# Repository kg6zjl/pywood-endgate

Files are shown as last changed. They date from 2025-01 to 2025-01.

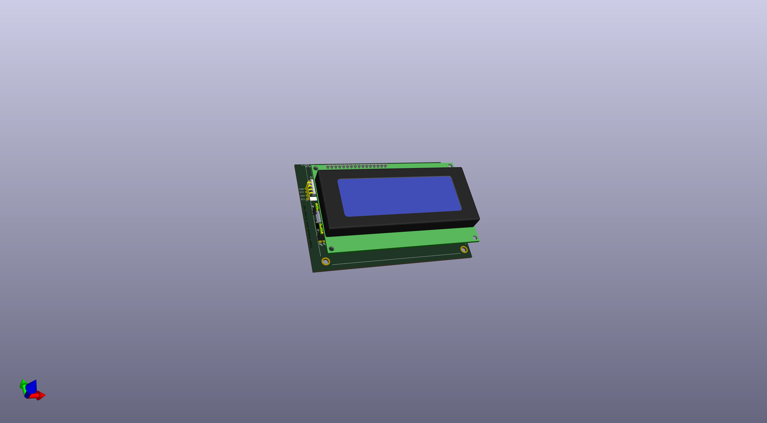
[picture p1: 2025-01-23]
hw/pine_derby_hw1.jpg

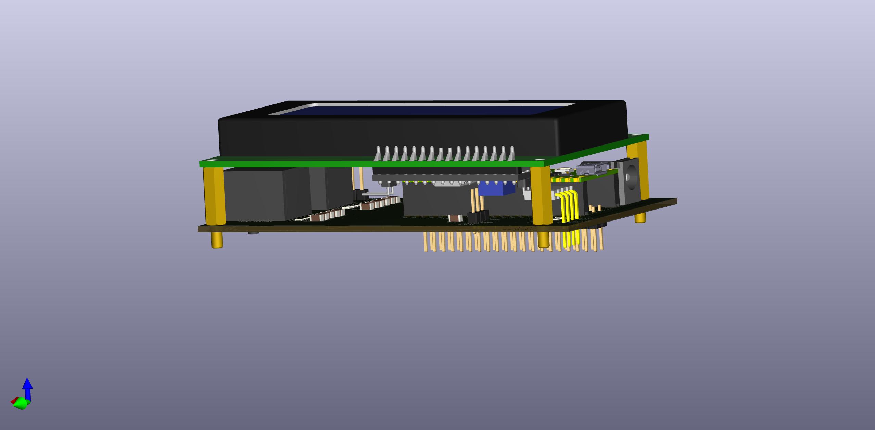
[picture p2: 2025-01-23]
hw/exports/pine_derby_hw_3.jpg

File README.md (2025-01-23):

Our scouting troop in TrailLifeUSA needs a way to identify which Pinewood Derby cars place first and second. We run two brackets, one for first place and one for second. Our current track is a 4 lane with manually operated lever gate for release.

I decided that from a K.I.S.S. standpoint, I don't care about timing the cars. Could be a future state, but for this iteration it doesn't matter. We really only care about the order that the cars reach the end gate.

This is my first time ever working at a PIO/hardware level, so feedback is appreciated. I'm learning along the way!

# Initial Design
- Micropython as the language
- Waveshare RP2040 Plus as the MCU
- 4 Row LCD for results
- A momentary reset button to trigger a display reset
- Light Dependent Resistors (Digital Module LM393) under the track, existing light source in endgate as primary light source

# Future State/Improvements/Ideas
- Add duplicate display at start gate so that bracket manager can see results on stage
- Add a microswitch at the start gate and add timing functionality
- Print race slips for winners with times? could be fun
- A camera/photo of the winner would be fun, especially if we setup a projector
- Automated bracket tracking?
- IR Break Beam sensors for end gate (introduces slightly more wiring, but same amount of programatic complexity I think)

# Notes
- When loading up RP2040, you have to load MicroPython first (see firmware)
- Then you have to copy all the project files over to RP2040
- Click "Run" in VSCode

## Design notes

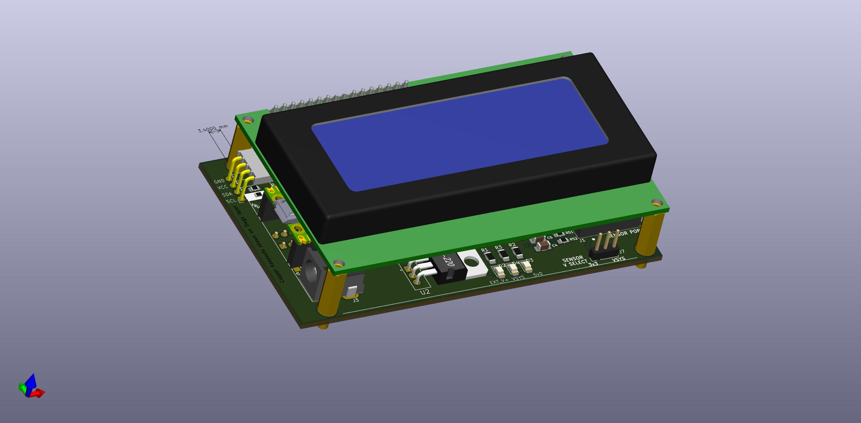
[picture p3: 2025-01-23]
hw/exports/pine_derby_hw_1.jpg

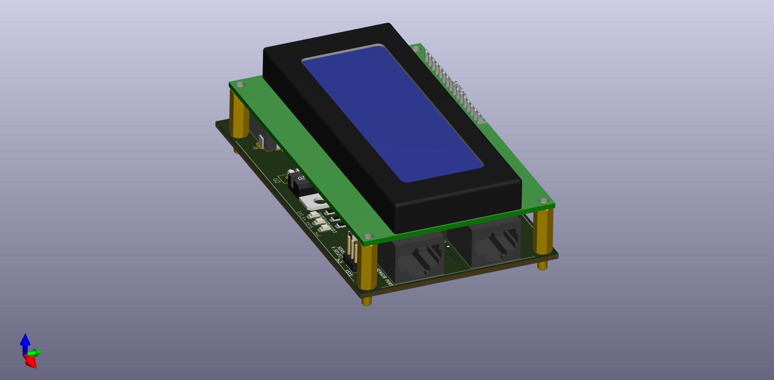
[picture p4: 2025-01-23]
hw/exports/pine_derby_hw_2.jpg

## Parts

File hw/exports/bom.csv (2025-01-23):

Reference | Value | Datasheet | Footprint | Qty | DNP | MPN
J3 | PJ-202AH | ~ | PJ-202AH:CUI_PJ-202AH | 1 |  | PJ-202AH
U2 | L7805CV |  | L7805CV:TO255P1040X460X1968-3 | 1 |  | L7805C-V
J1,J2 | 54602-908LF |  | 54602-908LF:AMPHENOL_54602-908LF | 2 |  | 54602-908LF
U1 | Pico |  | MCU_RaspberryPi_and_Boards:RPi_Pico_SMD_TH | 1
R4,R5,R6,R7,R8,R9,R10,R11,R12,R13,R14,R15,R16,R17,R18,R19,R20,R21,R22,R23,R24,R25,R26,R27,R28,R29,R30,R31,R32,R33,R34,R35,R36,R37,R38,R39,R40,R41,R42,R43,R44,R45,R46,R47,R48,R49,R50,R51,R52,R53,R54,R55,R56 | 0R | ~ | Resistor_SMD:R_0805_2012Metric_Pad1.20x1.40mm_HandSolder | 53 |  | RC0805JR-070RL
R1,R2,R3 | 3k | ~ | Resistor_SMD:R_1206_3216Metric_Pad1.30x1.75mm_HandSolder | 3 |  | RC1206JR-073KL
J6,J7 | Conn_01x03_Pin | ~ | Connector_PinHeader_2.54mm:PinHeader_1x03_P2.54mm_Vertical | 2 |  | 61300311121
J4,J5 | Conn_01x20_Pin | ~ | Connector_PinHeader_2.54mm:PinHeader_1x20_P2.54mm_Vertical | 2 |  | PH1-20-UA
DS1 | LCD-20X4B |  | LCD-20X48:LCD_LCD-20X4B | 1
D2,D3,D4 | LED-G | ~ | LED_SMD:LED_1206_3216Metric_Pad1.42x1.75mm_HandSolder | 3 |  | LTST-C150GKT
D1 | D | ~ | Diode_SMD:Nexperia_CFP3_SOD-123W | 1 |  | MBR230LSFT1G
C2,C3,C4,C5,C6,C7,C8,C9,C10,C11,C12,C13,C14,C15,C16 | 0.1uF | ~ | Capacitor_SMD:C_1206_3216Metric_Pad1.33x1.80mm_HandSolder | 15 |  | 1206B104K500CT
C1 | 0.33uF | ~ | Capacitor_SMD:C_1206_3216Metric_Pad1.33x1.80mm_HandSolder | 1 |  | CL31B334KBFNNNE

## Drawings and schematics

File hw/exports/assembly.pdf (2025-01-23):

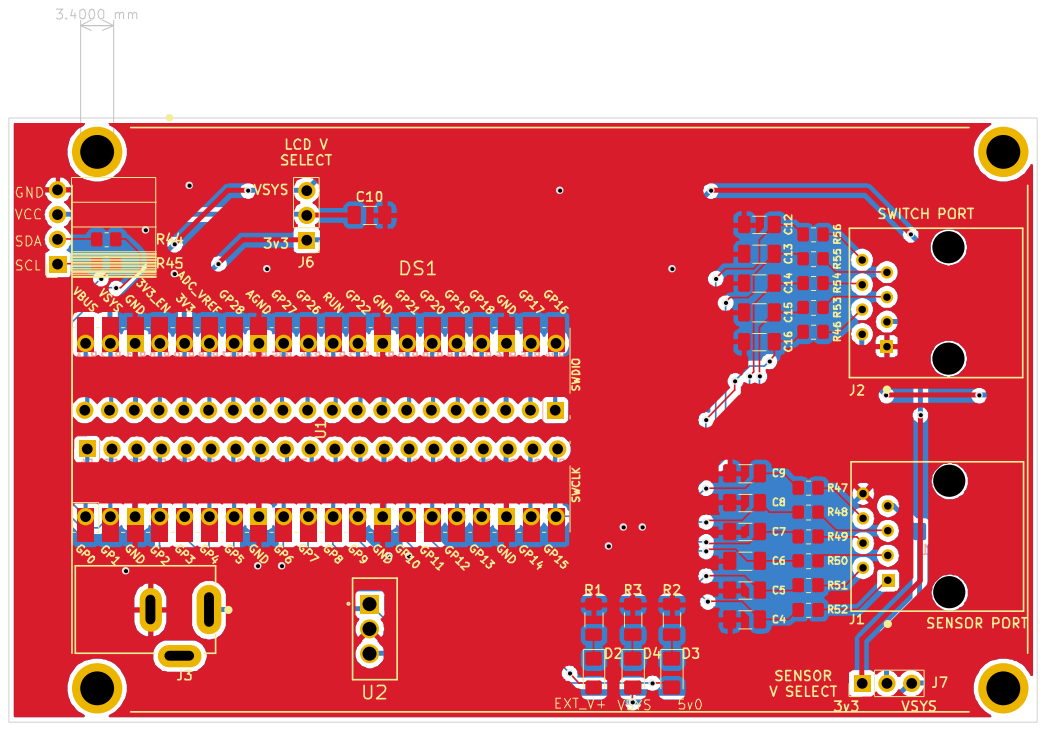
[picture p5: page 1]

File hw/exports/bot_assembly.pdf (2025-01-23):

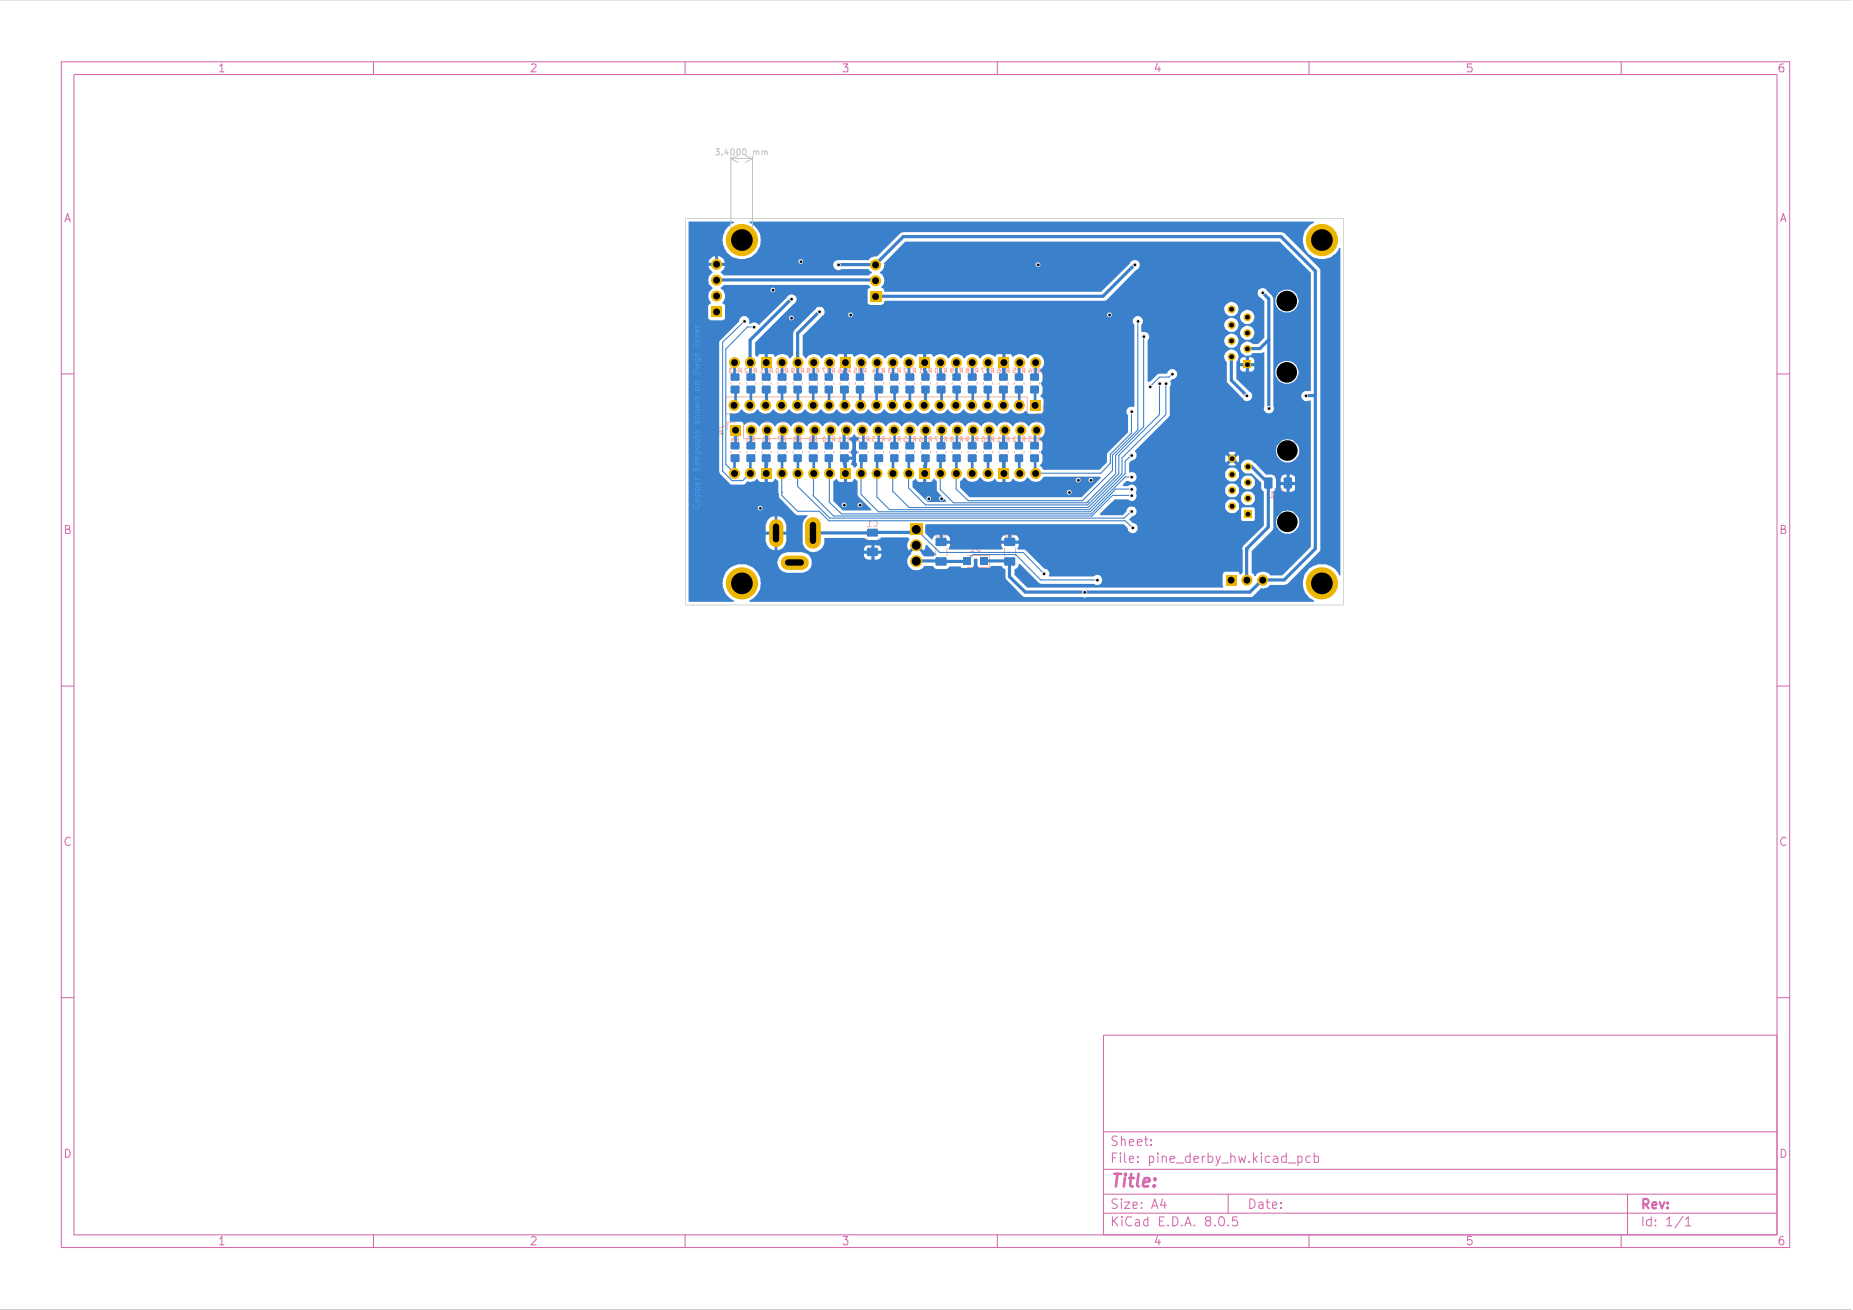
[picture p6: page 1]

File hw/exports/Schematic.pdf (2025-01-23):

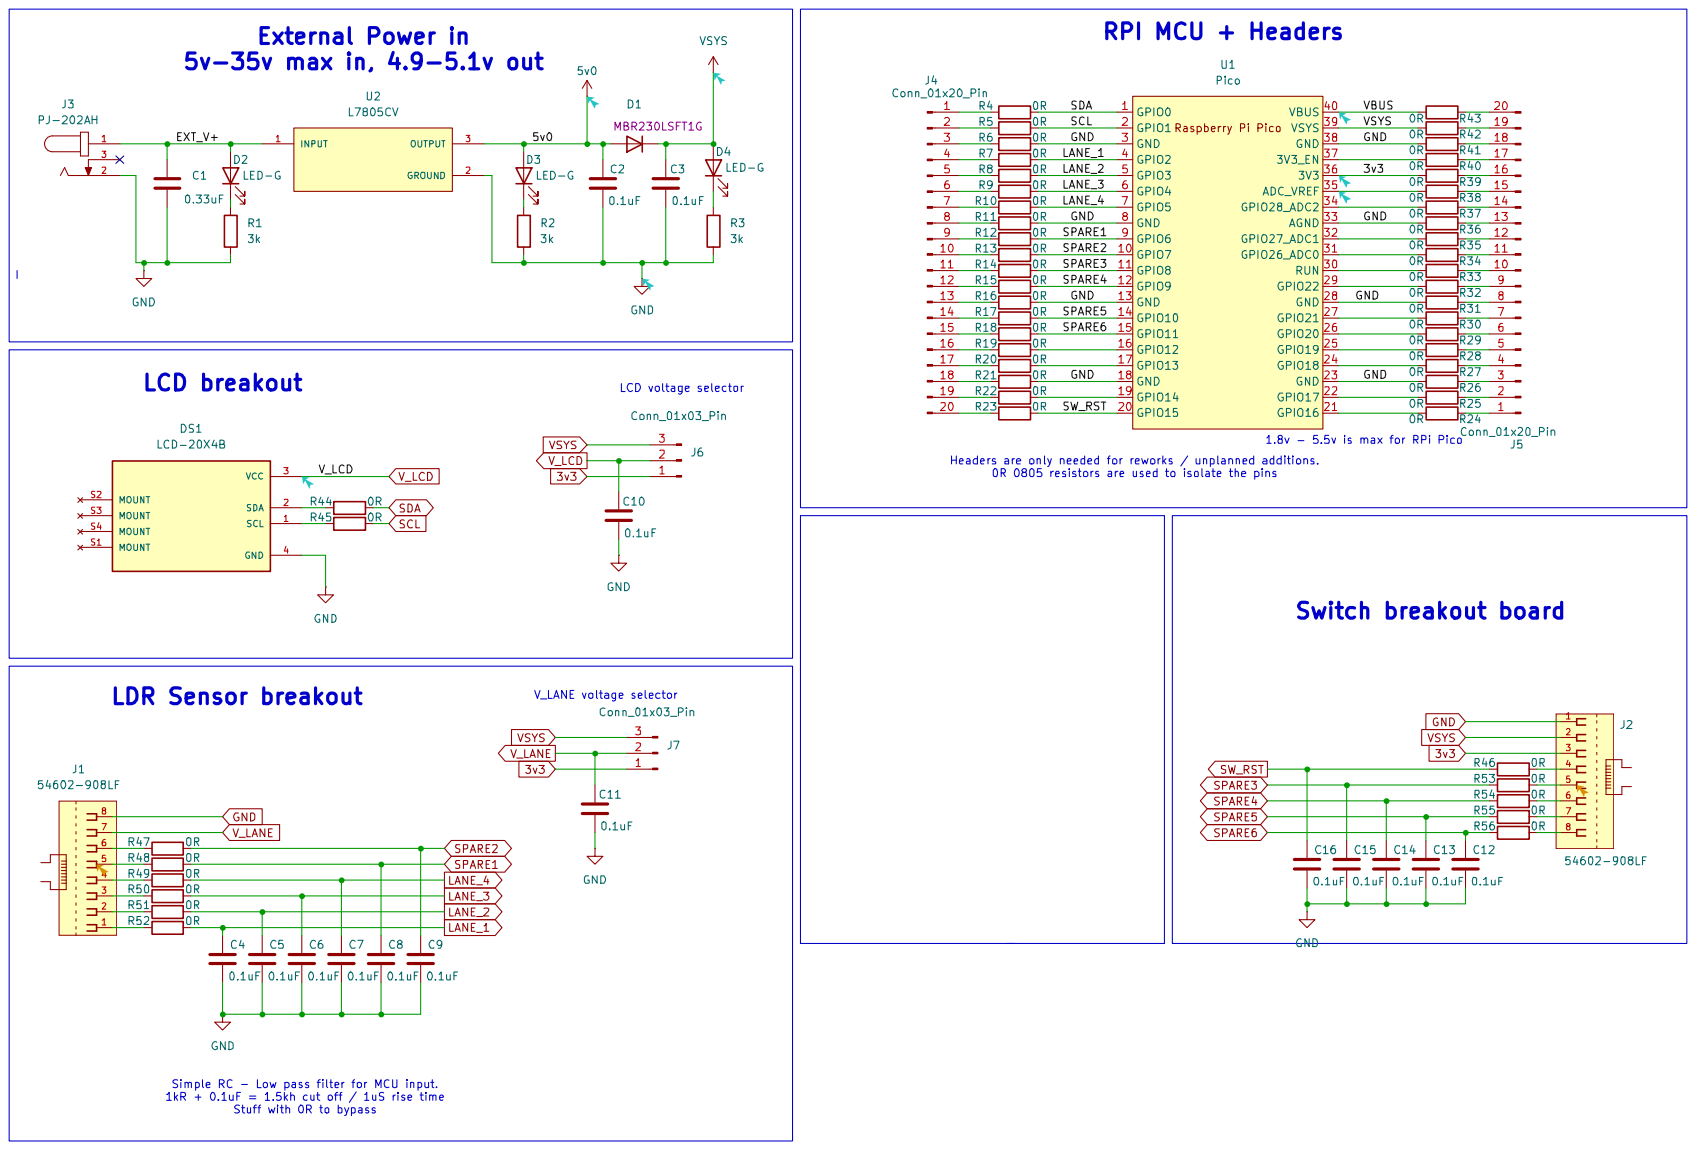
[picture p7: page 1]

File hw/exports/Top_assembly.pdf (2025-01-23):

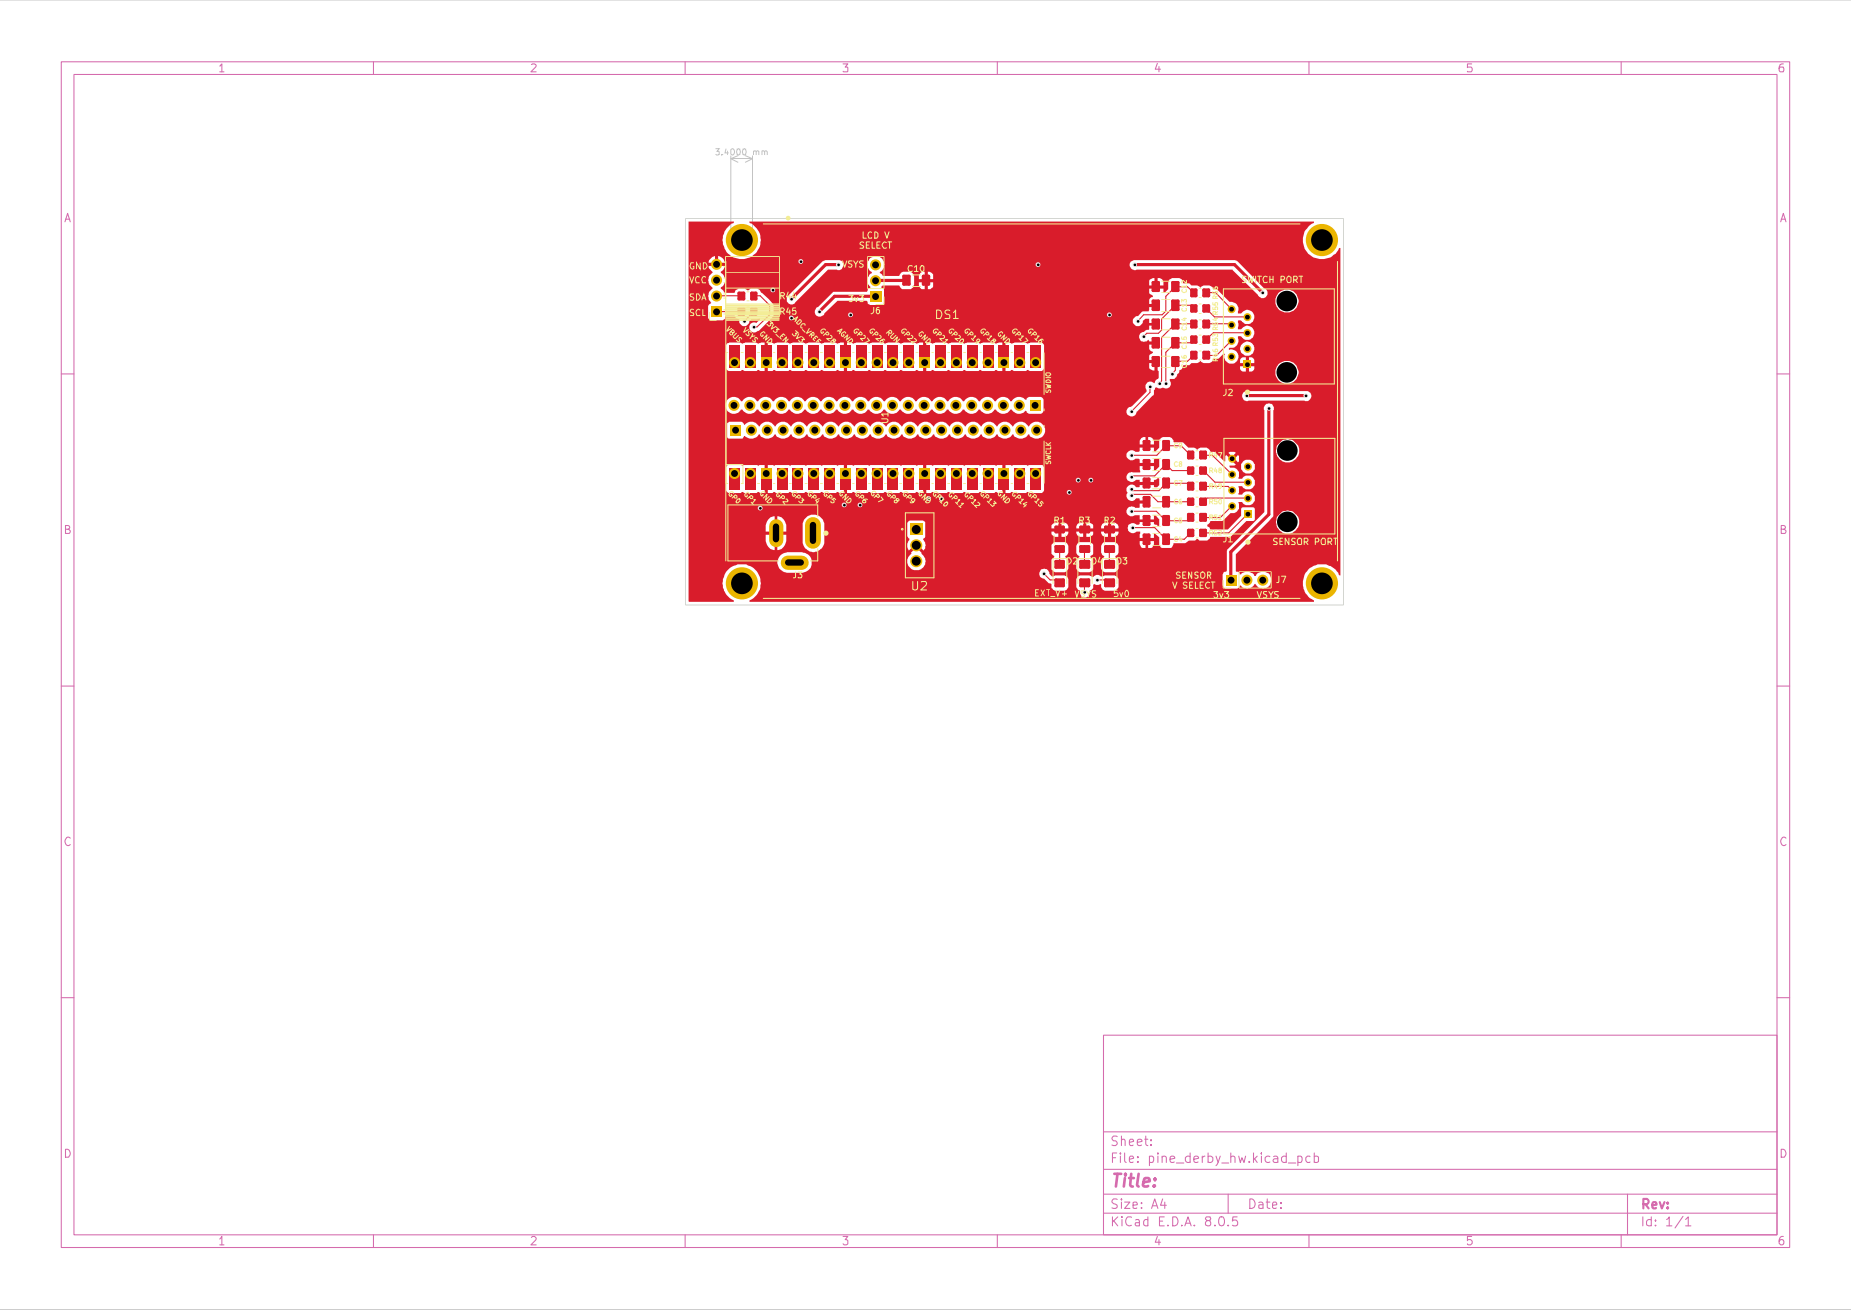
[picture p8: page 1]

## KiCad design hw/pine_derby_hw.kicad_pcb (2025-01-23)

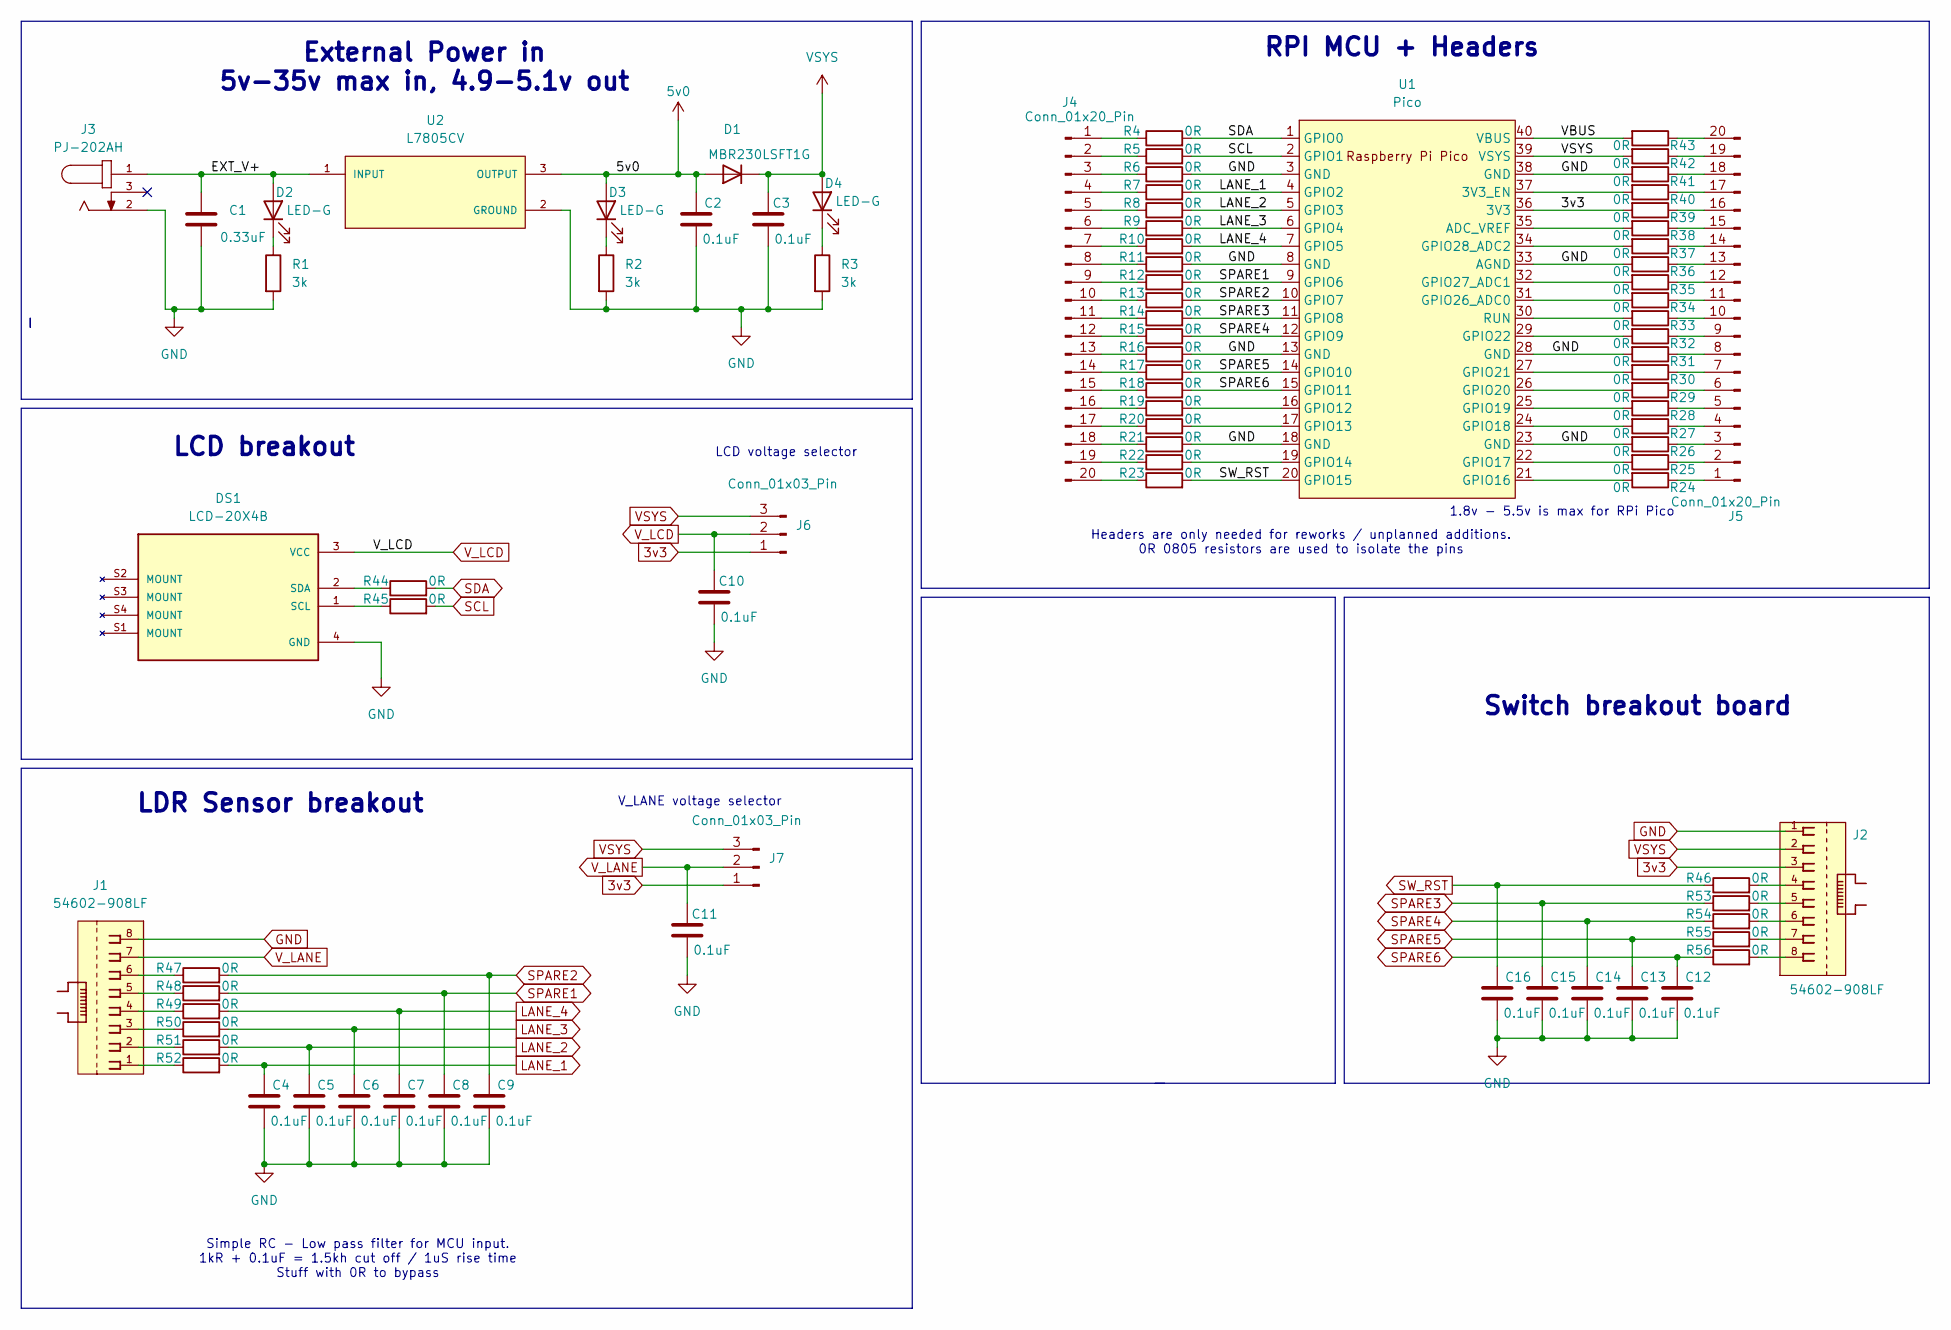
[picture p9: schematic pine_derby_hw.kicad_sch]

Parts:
C1: 0.33uF; C_1206_3216Metric_Pad1.33x1.80mm_HandSolder; MPN CL31B334KBFNNNE
C2, C3, C4, C5, C6, C7, C8, C9, C10, C11, C12, C13, C14, C15, C16: 0.1uF; C_1206_3216Metric_Pad1.33x1.80mm_HandSolder; MPN 1206B104K500CT
D1: D; Nexperia_CFP3_SOD-123W; MPN MBR230LSFT1G
D2, D3, D4: LED-G; LED_1206_3216Metric_Pad1.42x1.75mm_HandSolder; forward voltage 2.1v; MPN LTST-C150GKT
DS1: LCD-20X4B; LCD_LCD-20X4B
J1, J2: 54602-908LF; AMPHENOL_54602-908LF; PARTREV J
J3: PJ-202AH; CUI_PJ-202AH; PART_REV 1.02
J4, J5: Conn_01x20_Pin; PinHeader_1x20_P2.54mm_Vertical; MPN PH1-20-UA
J6, J7: Conn_01x03_Pin; PinHeader_1x03_P2.54mm_Vertical; MPN 61300311121
R1, R2, R3: 3k; R_1206_3216Metric_Pad1.30x1.75mm_HandSolder; MPN RC1206JR-073KL
R4, R5, R6, R7, R8, R9, R10, R11, R12, R13, R14, R15, R16, R17, R18, R19, R20, R21, R22, R23, R24, R25, R26, R27, R28, R29, R30, R31, R32, R33, R34, R35, R36, R37, R38, R39, R40, R41, R42, R43, R44, R45, R46, R47, R48, R49, R50, R51, R52, R53, R54, R55, R56: 0R; R_0805_2012Metric_Pad1.20x1.40mm_HandSolder; MPN RC0805JR-070RL
U1: Pico; RPi_Pico_SMD_TH
U2: L7805CV; TO255P1040X460X1968-3; PARTREV 36

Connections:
3v3: J2.3, J6.1, J7.1, R39.2, U1.36 (3V3)
5v0: C2.1, D1.2 (A), D3.2 (A), U2.3 (OUTPUT)
/EXT_V+: C1.1, D2.2 (A), J3.1, U2.1 (INPUT)
/VBUS: R43.2, U1.40 (VBUS)
GND: C1.2, C2.2, C3.2, C4.2, C5.2, C6.2, C7.2, C8.2, C9.2, C10.2, C11.2, C12.2, C13.2, C14.2, C15.2, C16.2, DS1.4 (GND), J1.8, J2.1, J3.2, R1.2, R2.2, R3.2, R6.2, R11.2, R16.2, R21.2, R26.2, R31.2, R36.2, R41.2, U1.3 (GND), U1.8 (GND), U1.13 (GND), U1.18 (GND), U1.23 (GND), U1.28 (GND), U1.33 (AGND), U1.38 (GND), U2.2 (GROUND)
LANE_1: C4.1, R7.2, R52.2, U1.4 (GPIO2)
LANE_2: C5.1, R8.2, R51.2, U1.5 (GPIO3)
LANE_3: C6.1, R9.2, R50.2, U1.6 (GPIO4)
LANE_4: C7.1, R10.2, R49.2, U1.7 (GPIO5)
unnamed: D2.1 (K), R1.1
unnamed: D3.1 (K), R2.1
unnamed: D4.1 (K), R3.1
unnamed: DS1.1 (SCL), R45.1
unnamed: DS1.2 (SDA), R44.1
unnamed: J1.1, R52.1
unnamed: J1.2, R51.1
unnamed: J1.3, R50.1
unnamed: J1.4, R49.1
unnamed: J1.5, R48.1
unnamed: J1.6, R47.1
unnamed: J2.4, R46.2
unnamed: J2.5, R53.2
unnamed: J2.6, R54.2
unnamed: J2.7, R55.2
unnamed: J2.8, R56.2
unnamed: J4.1, R4.1
unnamed: J4.2, R5.1
unnamed: J4.3, R6.1
unnamed: J4.4, R7.1
unnamed: J4.5, R8.1
unnamed: J4.6, R9.1
unnamed: J4.7, R10.1
unnamed: J4.8, R11.1
unnamed: J4.9, R12.1
unnamed: J4.10, R13.1
unnamed: J4.11, R14.1
unnamed: J4.12, R15.1
unnamed: J4.13, R16.1
unnamed: J4.14, R17.1
unnamed: J4.15, R18.1
unnamed: J4.16, R19.1
unnamed: J4.17, R20.1
unnamed: J4.18, R21.1
unnamed: J4.19, R22.1
unnamed: J4.20, R23.1
unnamed: J5.1, R24.1
unnamed: J5.2, R25.1
unnamed: J5.3, R26.1
unnamed: J5.4, R27.1
unnamed: J5.5, R28.1
unnamed: J5.6, R29.1
unnamed: J5.7, R30.1
unnamed: J5.8, R31.1
unnamed: J5.9, R32.1
unnamed: J5.10, R33.1
unnamed: J5.11, R34.1
unnamed: J5.12, R35.1
unnamed: J5.13, R36.1
unnamed: J5.14, R37.1
unnamed: J5.15, R38.1
unnamed: J5.16, R39.1
unnamed: J5.17, R40.1
unnamed: J5.18, R41.1
unnamed: J5.19, R42.1
unnamed: J5.20, R43.1
unnamed: R40.2, U1.37 (3V3_EN)
unnamed: R38.2, U1.35 (ADC_VREF)
unnamed: R19.2, U1.16 (GPIO12)
unnamed: R20.2, U1.17 (GPIO13)
unnamed: R22.2, U1.19 (GPIO14)
unnamed: R24.2, U1.21 (GPIO16)
unnamed: R25.2, U1.22 (GPIO17)
unnamed: R27.2, U1.24 (GPIO18)
unnamed: R28.2, U1.25 (GPIO19)
unnamed: R29.2, U1.26 (GPIO20)
unnamed: R30.2, U1.27 (GPIO21)
unnamed: R32.2, U1.29 (GPIO22)
unnamed: R34.2, U1.31 (GPIO26_ADC0)
unnamed: R35.2, U1.32 (GPIO27_ADC1)
unnamed: R37.2, U1.34 (GPIO28_ADC2)
unnamed: R33.2, U1.30 (RUN)
SCL: R5.2, R45.2, U1.2 (GPIO1)
SDA: R4.2, R44.2, U1.1 (GPIO0)
SPARE1: C8.1, R12.2, R48.2, U1.9 (GPIO6)
SPARE2: C9.1, R13.2, R47.2, U1.10 (GPIO7)
SPARE3: C15.1, R14.2, R53.1, U1.11 (GPIO8)
SPARE4: C14.1, R15.2, R54.1, U1.12 (GPIO9)
SPARE5: C13.1, R17.2, R55.1, U1.14 (GPIO10)
SPARE6: C12.1, R18.2, R56.1, U1.15 (GPIO11)
SW_RST: C16.1, R23.2, R46.1, U1.20 (GPIO15)
VSYS: C3.1, D1.1 (K), D4.2 (A), J2.2, J6.3, J7.3, R42.2, U1.39 (VSYS)
V_LANE: C11.1, J1.7, J7.2
V_LCD: C10.1, DS1.3 (VCC), J6.2

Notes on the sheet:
LCD breakout
Simple RC - Low pass filter for MCU input. 1kR + 0.1uF = 1.5kh cut off / 1uS rise time Stuff with 0R to bypass
1.8v - 5.5v is max for RPi Pico
Headers are only needed for reworks / unplanned additions. 0R 0805 resistors are used to isolate the pins
Switch breakout board
LDR Sensor breakout
External Power in 5v-35v max in, 4.9-5.1v out
LCD voltage selector
V_LANE voltage selector
RPI MCU + Headers

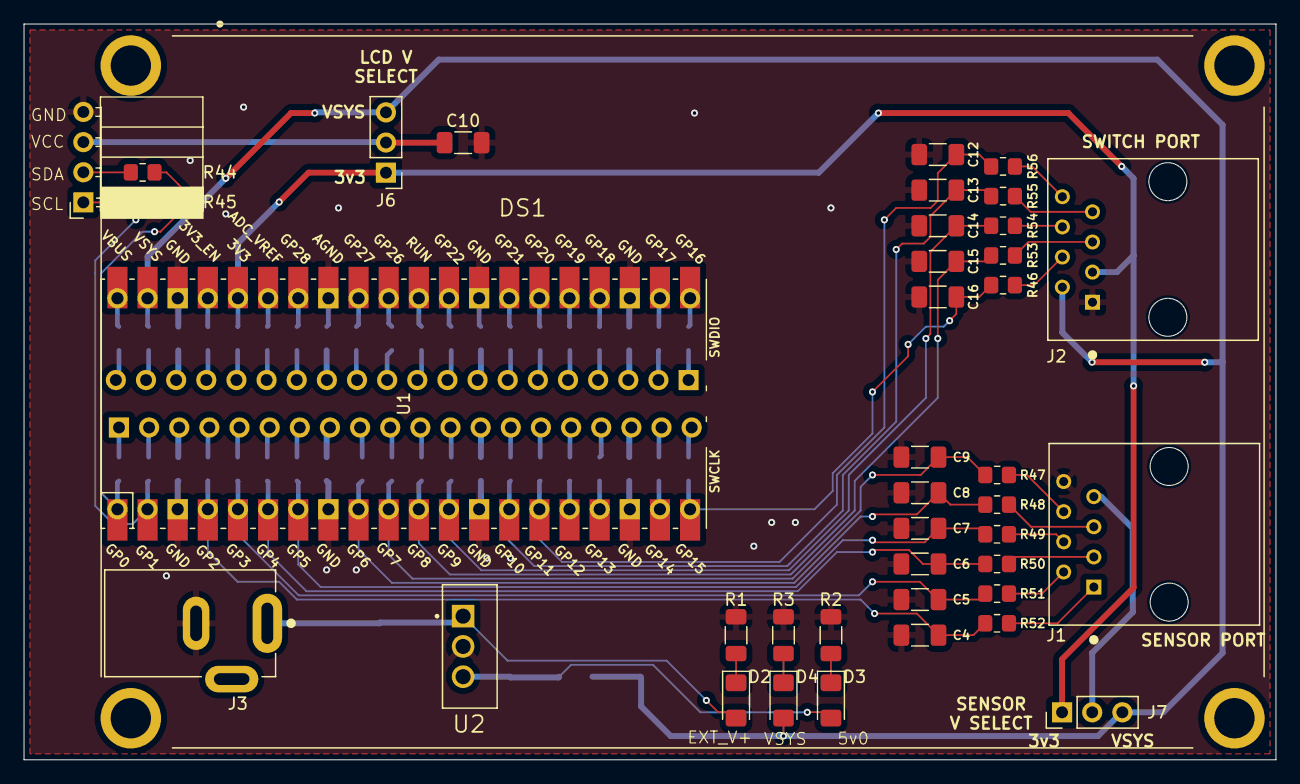
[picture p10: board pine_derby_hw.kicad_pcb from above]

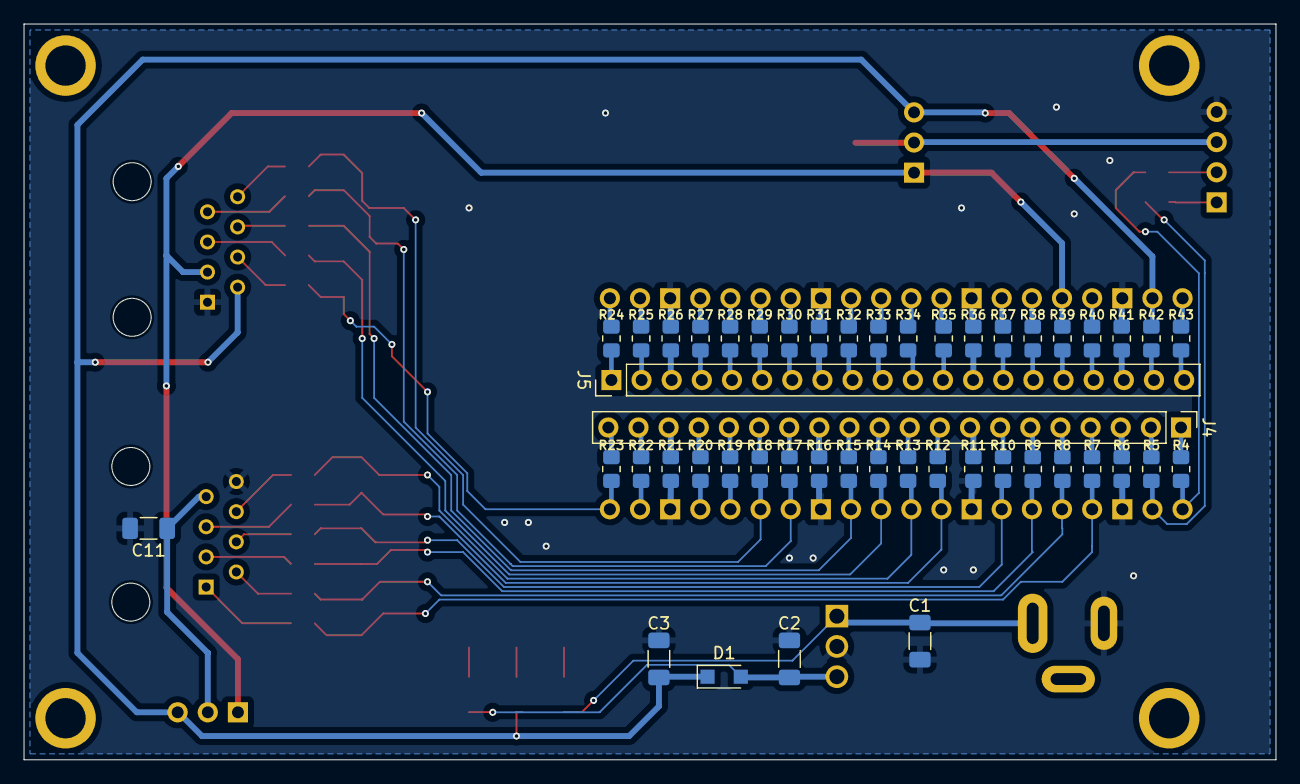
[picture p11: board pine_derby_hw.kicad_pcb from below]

Board: 2 copper layers, 105.5 x 62.0 mm, 86 parts (47 on the bottom side), 93 nets.

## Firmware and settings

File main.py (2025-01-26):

import networking
from machine import Pin, SoftI2C
from pico_i2c_lcd import I2cLcd
from time import sleep
import uasyncio as asyncio
import urequests as requests
import json
import utime

# LCD I2C address
LCD_ADDR = 0x27
# rows/columns
LCD_ROWS = 4
LCD_COLS = 20

# Path to config file
CONFIG_PATH = 'config.json'

# map out each lane to ldr sensor, add more lanes/sensors here
LDR_PIN_MAP = {
    2: {"lane": 1},
    3: {"lane": 2},
    4: {"lane": 3},
    5: {"lane": 4},
}

# add more places here if more than 4 lanes/places
PLACES = [
    "FIRST",
    "SECOND",
    "THIRD",
    "FOURTH",
]

# Constants
RESET_BTN_PIN = Pin(15, Pin.IN, Pin.PULL_UP)
LDR_PINS = list(LDR_PIN_MAP.keys())
LANE_COUNT = len(LDR_PINS)
LDR_SENSORS = [Pin(pin, Pin.IN) for pin in LDR_PINS]
CLOCK_PIN = Pin(6, Pin.OUT)
LCD_SDA = Pin(0)
LCD_SCL = Pin(1)

# Debounce vars and tracking time diff per sensor/pin
DEBOUNCE_TIME = 50
last_trigger_time = {pin: 0 for pin in LDR_PINS}

# Global race variables
RANK = []
RESULTS = {}
STOP_UPDATES = False

# networking/rest calls
HEADERS = {'Content-Type': 'application/json'}

class MockLCD:
    def __init__(self):
        pass

    def move_to(self, x, y):
        pass

    def putstr(self, s):
        print(f"{s} \n", end='')

    def clear(self):
        pass

    def home(self):
        pass

    def backlight_off(self):
        pass
    
    def display_off(self):
        pass

# Initialize I2C and LCD objects
try:
    i2c = SoftI2C(sda=LCD_SDA, scl=LCD_SCL, freq=400000)
    lcd = I2cLcd(i2c, LCD_ADDR, LCD_ROWS, LCD_COLS)
except:
    print("Running without LCD")
    lcd = MockLCD()
    sleep(1)
    lcd.clear()

def read_config(file_path):
    try:
        with open(file_path, 'r') as file:
            config = json.load(file)
        return config
    except Exception as e:
        print(f"An unexpected error occurred: {e}")
        return False

def reset():
    global RANK, STOP_UPDATES, RESULTS
    # Clear LCD for next race
    lcd.clear()
    # Reset for next race
    RANK = []
    RESULTS = {}
    # Resume display updates
    STOP_UPDATES = False
    lcd_writer(["READY TO RACE","","",""])
    sleep(0.1)

# Interrupt handler for reset button
def reset_button_handler(pin):
    if pin.value() == 0:
        reset()
        send_reset()

# Configure interrupt for reset button
RESET_BTN_PIN.irq(trigger=Pin.IRQ_FALLING, handler=reset_button_handler)

def lcd_writer(lines):
    i = 0
    for line in lines:
        lcd.move_to(0, i)
        lcd.putstr(line)
        i += 1

def update_lcd_rank(rank, lane):
    lcd.move_to(0, rank)
    lcd.putstr(f"{ PLACES[rank] }: { lane }")

def ldr_callback(pin):
    global RANK, RESULTS
    current_time = utime.ticks_ms()
    for i, ldr_pin in enumerate(LDR_SENSORS):
        if ldr_pin == pin:
            # Check debounce time for this specific sensor
            if utime.ticks_diff(current_time, last_trigger_time[LDR_PINS[i]]) > DEBOUNCE_TIME:
                lane = f"LANE {LDR_PIN_MAP[LDR_PINS[i]]['lane']}"
                # Only append lanes that have not previously ranked
                if lane not in RANK:
                    RANK.append(lane)
                    update_lcd_rank(len(RANK) - 1, lane)
                    RESULTS[PLACES[len(RANK) - 1]] = LDR_PIN_MAP[LDR_PINS[i]]['lane']
                    last_trigger_time[LDR_PINS[i]] = current_time
                    break

# Configure interrupts instead of looping over each sensor and checking state
for ldr_sensor in LDR_SENSORS:
    # we trigger on rising voltage, but we could also trigger on the falling edge: Pin.IRQ_FALLING
    ldr_sensor.irq(trigger=Pin.IRQ_RISING, handler=ldr_callback)

async def send_results():
    global RESULTS
    url = f"{ ENDPOINT }/api/v1/results"
    while True:
        if RANK:
            try:
                response = requests.post(url, json=RESULTS, headers=HEADERS)
                print(RESULTS)
                if response.status_code == 201:
                    print("Data sent successfully")
                else:
                    print("Failed to send data")
                response.close()
            except Exception as e:
                print(f"Error sending data: {e}")
        await asyncio.sleep(0.1)

def send_reset():
    url = f"{ ENDPOINT }/api/v1/reset"
    print("Sending reset")
    try:
        response = requests.post(url, headers=HEADERS)
        if response.status_code == 200:
            print("Reset sent successfully")
            response.close()
        else:
            print("Failed to send reset")
    except Exception as e:
        print(f"Error sending reset: {e}")

async def main():
    global STOP_UPDATES, RANK, LANE_COUNT, SERVER, ENDPOINT

    # Start the data sending task
    asyncio.create_task(send_results())
    
    try:
        # Main loop to check sensors and update display
        while True:
            # Once the last place registers, we can stop updating the
            # display on each cycle until the reset button is pressed
            if len(RANK) == LANE_COUNT:
                STOP_UPDATES = True

            await asyncio.sleep(0.1)  # reset button debounce
    except KeyboardInterrupt:
        # Turn off the display
        print("Shutting down...")
        lcd.backlight_off()
        lcd.display_off()

try:
    config = read_config(CONFIG_PATH)
    if config:
        network_config = config.get('networking')
        WIFI_SSID = network_config.get('ssid')
        WIFI_PASSWORD = network_config.get('password')
        SERVER = network_config.get('apiserver')
        PORT = network_config.get('port')
        PROTOCOL = network_config.get('protocol')
        ENDPOINT = f"{PROTOCOL}://{ SERVER }:{ PORT }"
    else:
        lcd.clear()
        lcd_writer(["","Failed to","read config",""])
    if network_config.get('enabled'):
        lcd.clear()
        lcd_writer(["Connecting to","WIFI SSID:",WIFI_SSID,""])
        try:
            if networking.connect_wifi(WIFI_SSID, WIFI_PASSWORD):
                lcd.clear()
                lcd_writer(["","Wifi Connected:",WIFI_SSID,""])
                sleep(1)
            else:
                lcd.clear()
                lcd_writer(["Failed to","connect to",WIFI_SSID,""])
        except:
            lcd.clear()
            lcd_writer(["Failed to","connect to",WIFI_SSID,""])
    
    # Welcome msg
    lcd.clear()
    lcd_writer(["Welcome to","PyWood Endgate","Starting","Derby Race!"])
    sleep(2)
    lcd.clear()

    # start our async main loop
    asyncio.run(main())

except KeyboardInterrupt:
    # Turn off the display
    print("Shutting down...")
    lcd.backlight_off()
    lcd.display_off()

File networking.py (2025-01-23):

import network
import time

def connect_wifi(ssid, password):
    connected = False

    # Initialize the network interface
    wlan = network.WLAN(network.STA_IF)
    wlan.active(True)

    # disconnect if already connected
    if wlan.isconnected():
        wlan.disconnect()

    # Connect to the Wi-Fi network
    wlan.connect(ssid, password)

    # Wait for connection
    max_attempts = 10
    attempts = 0
    while not wlan.isconnected() and attempts < max_attempts:
        print('Connecting to network...')
        time.sleep(2)
        attempts += 1

    # Check if connected
    if wlan.isconnected():
        print('Connected to', ssid)
        print('Network config:', wlan.ifconfig())
        connected = True
    else:
        print('Failed to connect to', ssid)
        connected = False

    return connected

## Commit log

2024-08-27 Init commit for micropython based endgate to track how each lane places
2024-08-27 use ldr pin map to write lane number to RANK
2024-08-27 Update main.py
    define clock output pin
2025-01-23 adding networking features and hardware spec
    [bom.csv, pine_derby_hw.kicad_pcb, pine_derby_hw.kicad_sch]
2025-01-26 sensors on interrupts and networking
